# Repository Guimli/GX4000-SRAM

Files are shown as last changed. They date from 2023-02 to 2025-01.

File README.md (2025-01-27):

# GX4000-SRAM

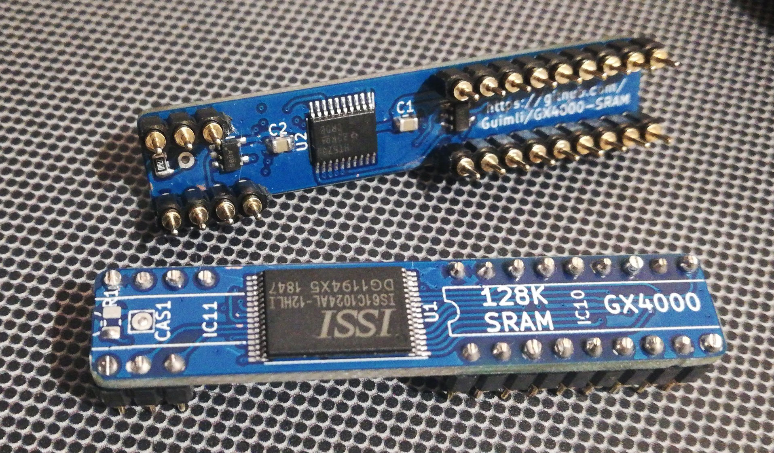
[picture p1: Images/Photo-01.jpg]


RAM replacement mod for GX4000 based on modern RAM. This mod can be used to replace the original RAM of the GX4000. And it is also possible to expand the GX4000's RAM to 128K.

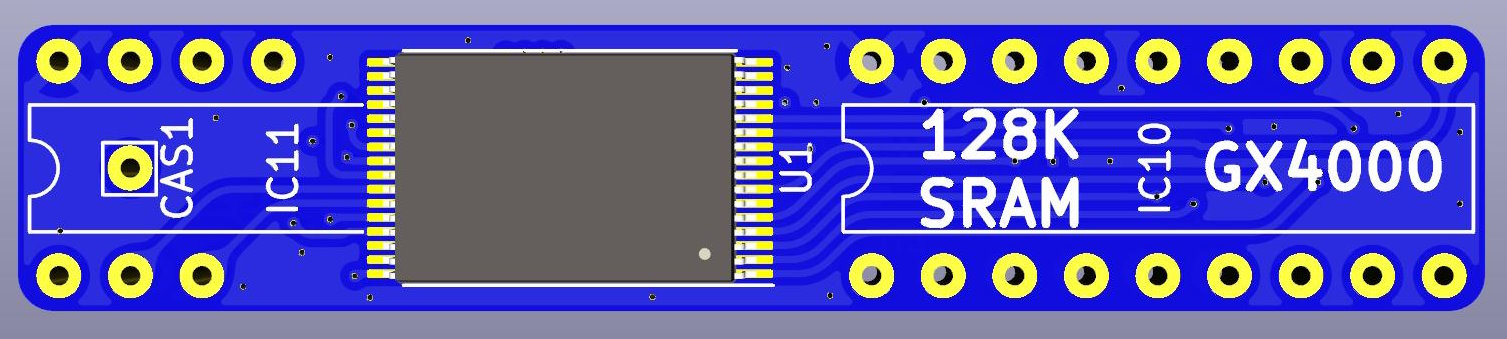
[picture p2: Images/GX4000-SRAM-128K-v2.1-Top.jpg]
Top

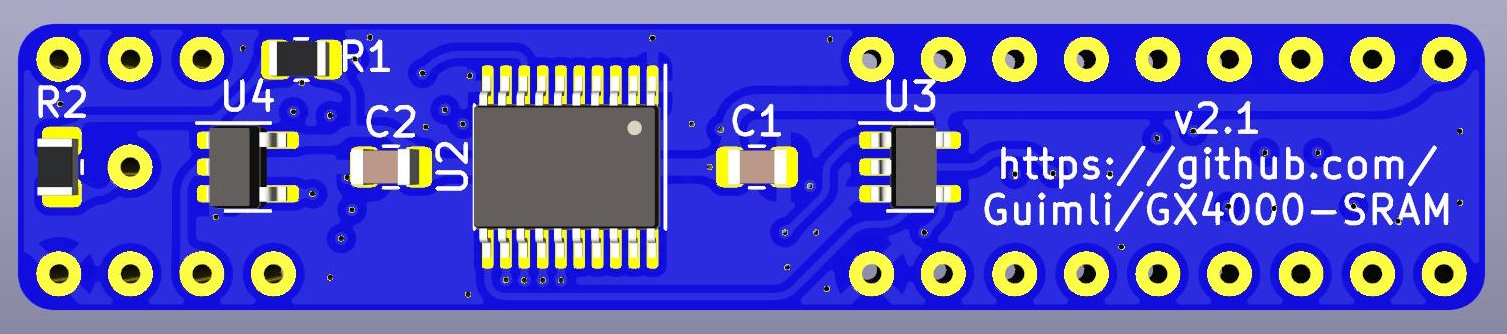
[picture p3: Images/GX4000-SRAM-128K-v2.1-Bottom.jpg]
Bottom


This mod is inspired by the SRAM for C64 on https://github.com/jamarju/c64-sram

Video of the installation of this mod on the Twitch of RetroRedrum :
RetroRedrum - Amstrad GX4000 - 128k S-Ram mod (https://www.youtube.com/watch?v=3vgKoG_qG3Q "RetroRedrum - Amstrad GX4000 - 128k S-Ram mod")

Approximate cost for one RAM mod (costs can be considerably reduced if you build several modules) :

- IS61C1024AL-12HLI : 3.28 €
- SN74HCT573PWR : 0.58 €
- SN74LVC1G08DBVR : 0.36 €
- SN74LVC1G32DBVR : 0.38 €
- R1 & R2 : 0.10 €
- C1 & C2 : 0.84 €
- PCB (minimum 5 + Shipping) : 14.95€
- IC10 & IC11 (Headers 20 pin) : 2.49€
- Round Pinheader (10x 1x40) : 8.19€

Total : 31,32€

I can sell you modules already assembled. But the shipping costs from France are prohibitive...

To enable the 128K mod, add a 10 kΩ resistor between pins 8 and 11 of IC8 (74HC4051).
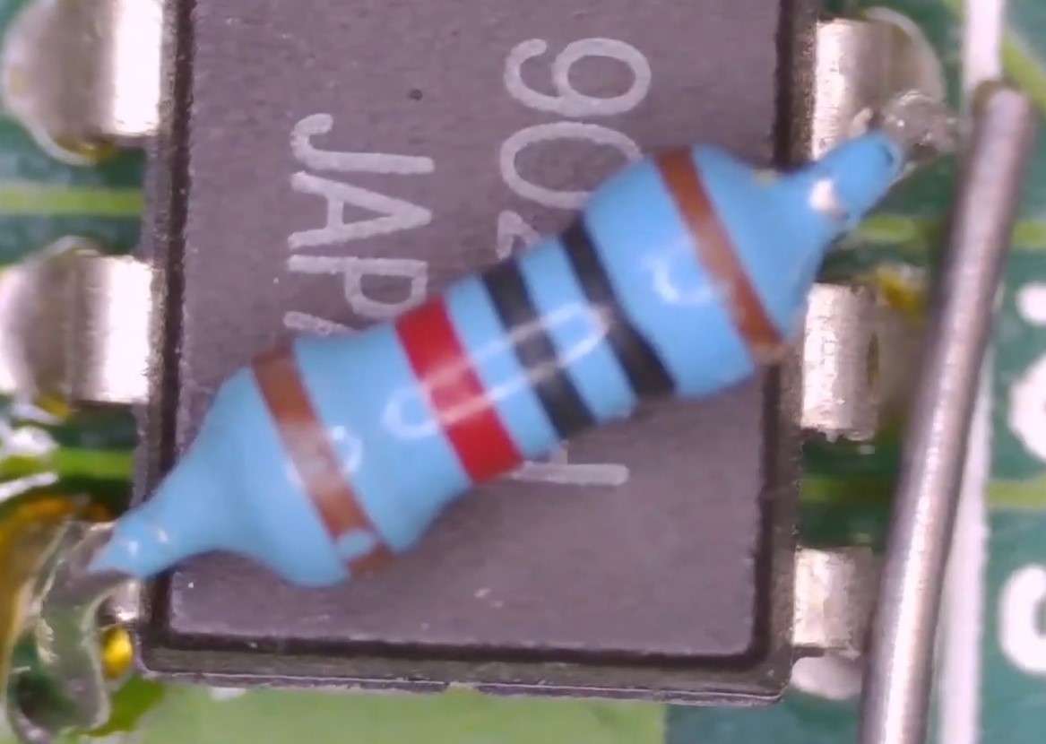
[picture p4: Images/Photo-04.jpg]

And connect pin 91 of the ASIC to the dedicated CAS1 slot on the mod.
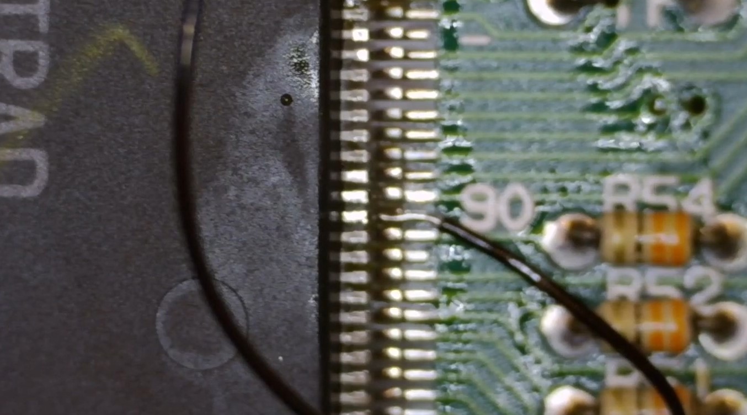
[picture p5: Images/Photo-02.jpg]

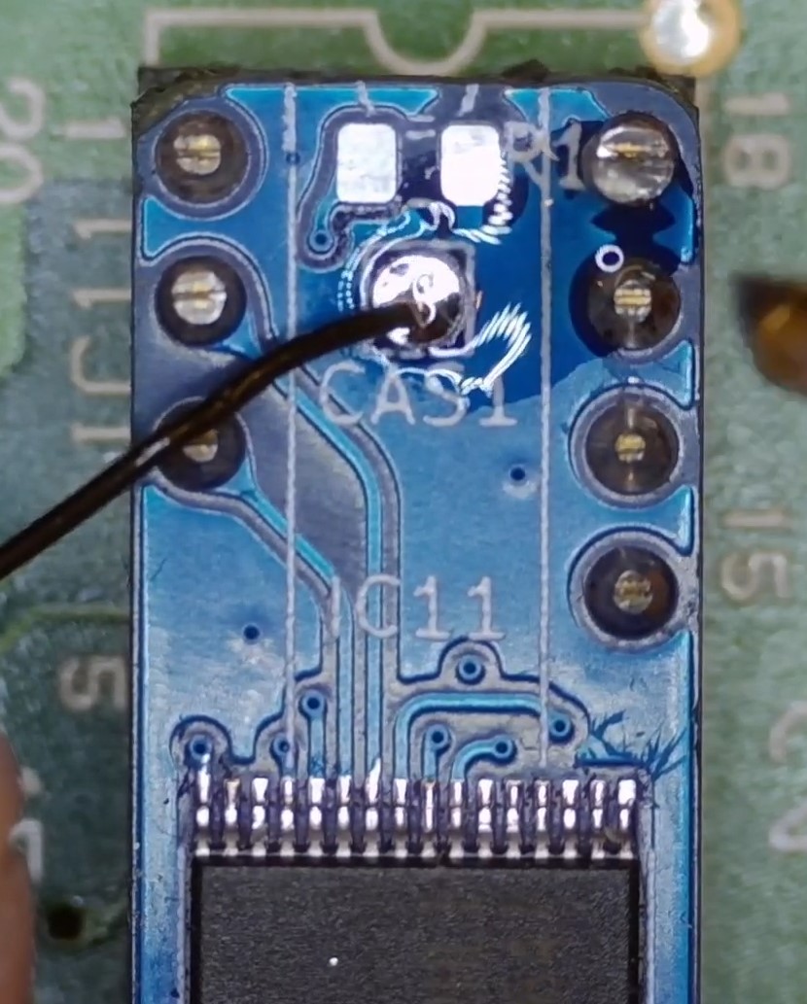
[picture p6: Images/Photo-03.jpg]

(See https://www.cpcwiki.eu/index.php/128k_on_GX-4000 for more information)

## BOM
| Quantity | Description | Part Number | Mouser | Notes |
|:---:|:---|---|---|---|
| 1 | SRAM 1Mbit pin 32 TSOP I-32 | IS61C1024AL-12HLI | [870-61C1024AL-12HLI](https://www.mouser.fr/ProductDetail/ISSI/IS61C1024AL-12HLI?qs=NHlAyh8rbXxX6sVqjKW4FQ%3D%3D) | |
| 1 | 74HCT573 pin 20 TSSOP | SN74HCT573PWR | [595-SN74HCT573PWR](https://www.mouser.fr/ProductDetail/Texas-Instruments/SN74HCT573PWR?qs=CCO124VRWrmt55RoEPLmzg%3D%3D) | |
| 1 | 74LVC1G32 pin 5 SOT-23-5 | SN74LVC1G32DBVR  | [595-SN74LVC1G32DBVR](https://www.mouser.fr/ProductDetail/Texas-Instruments/SN74LVC1G32DBVR?qs=3pnr37ZAbK%2F6ArGi%2FPb2Ng%3D%3D) | |
| 1 | 74LVC1G08 pin 5 SOT-23-5 | SN74LVC1G08DBVR  | [595-SN74LVC1G08DBVR](https://www.mouser.fr/ProductDetail/Texas-Instruments/SN74LVC1G08DBVR?qs=8yeEWhuAOtNjtL049wSCoQ%3D%3D) | |
| 2 | 100nf / 0.1uf Ceramic Capacitor 0805 Size | C0805C104K5RAC7411 | [80-C0805C104K5RACLR](https://www.mouser.fr/ProductDetail/KEMET/C0805C104K5RAC7411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) | Any 100nf 0805 is fine |
| 1 | 47K Ohm resistor 0805 Size | CR0805-JW-473ELF  | [652-CR0805JW-473ELF](https://www.mouser.fr/ProductDetail/Bourns/CR0805-JW-473ELF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) | Any 47KΩ 0805 resistor is fine |
| 1 | 33 Ohm resistor 0805 Size | CR0805-JW-330ELF | [652-CR0805JW-330ELF ](https://www.mouser.fr/ProductDetail/Bourns/CR0805-JW-330ELF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) | Any 33Ω 0805 resistor is fine |

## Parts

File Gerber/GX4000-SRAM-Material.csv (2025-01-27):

Id | Référence | Empreinte | Quantité | Désignation | Fournisseur et réf
1 | U1 | TSOP-I-32_11.8x8mm_P0.5mm | 1 | IS61C1024AL-12HLI
2 | IC10,IC11 | DIP-18_W7.62mm_LongPads | 2 | TMS4464
3 | CAS1 | Pin_D0.7mm_L6.5mm_W1.8mm_FlatFork | 1 | Conn_01x01
4 | U4 | SOT-23-5 | 1 | 74LVC1G08
5 | C1,C2 | C_0805_2012Metric | 2 | 100nF
6 | U2 | TSSOP-20_4.4x6.5mm_P0.65mm | 1 | 74HCT573
7 | U3 | SOT-23-5 | 1 | 74LVC1G32
8 | R1 | R_0805_2012Metric | 1 | 47k
9 | R2 | R_0805_2012Metric | 1 | 33

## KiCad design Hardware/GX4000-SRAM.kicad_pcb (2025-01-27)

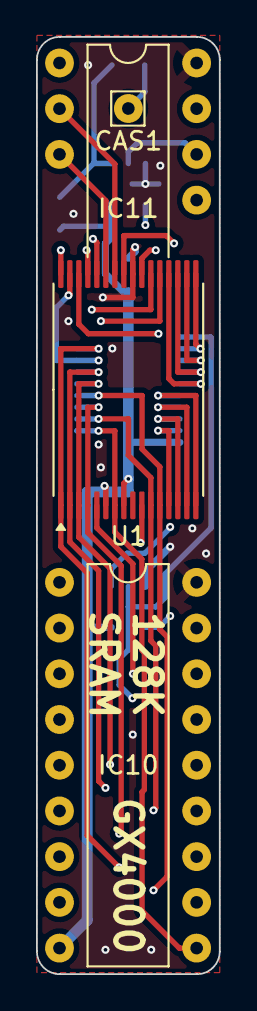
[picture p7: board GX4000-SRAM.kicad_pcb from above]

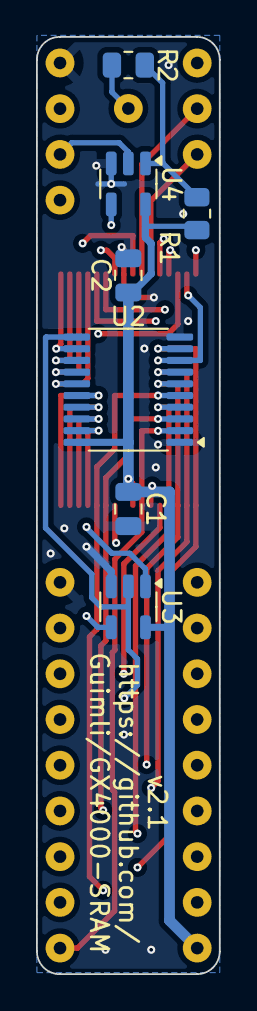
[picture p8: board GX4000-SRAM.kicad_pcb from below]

Board: 4 copper layers, 10.2 x 52.1 mm, 11 parts (7 on the bottom side), 34 nets.

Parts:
C1, C2: 100nF; C_0805_2012Metric
CAS1: Conn_01x01; Pin_D0.7mm_L6.5mm_W1.8mm_FlatFork
IC10, IC11: TMS4464; DIP-18_W7.62mm_LongPads
R1: 47k; R_0805_2012Metric
R2: 33; R_0805_2012Metric
U1: IS61C1024AL-12HLI; TSOP-I-32_11.8x8mm_P0.5mm
U2: SN74HCT573PWR; TSSOP-20_4.4x6.5mm_P0.65mm
U3: 74LVC1G32; SOT-23-5
U4: 74LVC1G08; SOT-23-5

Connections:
/A0: U1.20 (A0), U2.15 (Q4)
/A1: U1.19 (A1), U2.14 (Q5)
/A2: U1.18 (A2), U2.13 (Q6)
/A3: U1.17 (A3), U2.12 (Q7)
/A4: U1.16 (A4), U2.16 (Q3)
/A5: U1.15 (A5), U2.17 (Q2)
/A6: U1.14 (A6), U2.18 (Q1)
/A7: U1.13 (A7), U2.19 (Q0)
/D0: IC10.2 (DQ1), U1.21 (I/O0)
/D1: IC10.3 (DQ2), U1.22 (I/O1)
/D2: IC10.15 (DQ3), U1.23 (I/O2)
/D3: IC10.17 (DQ4), U1.25 (I/O3)
/D4: IC11.2 (DQ1), U1.26 (I/O4)
/D5: IC11.3 (DQ2), U1.27 (I/O5)
/D6: IC11.15 (DQ3), U1.28 (I/O6)
/D7: IC11.17 (DQ4), U1.29 (I/O7)
/MA0: IC10.14 (A0), U1.3 (A8), U2.6 (D4)
/MA1: IC10.13 (A1), U1.2 (A9), U2.7 (D5)
/MA2: IC10.12 (A2), U1.31 (A10), U2.8 (D6)
/MA3: IC10.11 (A3), U1.1 (A11), U2.9 (D7)
/MA4: IC10.8 (A4), U1.12 (A12), U2.5 (D3)
/MA5: IC10.7 (A5), U1.4 (A13), U2.4 (D2)
/MA6: IC10.6 (A6), U1.11 (A14), U2.3 (D1)
/MA7: IC10.10 (A7), U1.7 (A15), U2.2 (D0)
/~CAS0: IC10.16 (~CAS), IC11.16 (~CAS), U1.10 (A16), U4.2
/~CAS1: R1.2, R2.2, U4.1
/~OE: IC10.1 (~G), IC11.1 (~G), U1.32 (~OE)
/~RAS: IC10.5 (~RAS), U2.11 (Load), U3.2
/~WE: IC10.4 (~W), U1.5 (~WE)
GND: C1.2, C2.2, IC10.18 (GND), IC11.18 (GND), U1.24 (GND), U2.1 (OE), U2.10 (GND), U3.3 (GND), U4.3 (GND)
unnamed: CAS1.1, R2.1
unnamed: U1.30 (~CE1), U3.4
unnamed: U3.1, U4.4
VCC: C1.1, C2.1, IC10.9 (VCC), R1.1, U1.6 (CE2), U1.8 (VDD), U2.20 (VCC), U3.5 (VCC), U4.5 (VCC)

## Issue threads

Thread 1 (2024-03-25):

[QUESTION] How to contact

nico7550, 2024-03-25:
Hi, how to contact you to buy the premade ram module ?

Salut, comment te contacter pour acheter des modules de RAM déjà fait ? (accessoirement est-ce que tu accepterais de modder (_résistances, régulateur de tension, ram, acid bypass for BackBit Pro_) ma console contre rémunération ?)

Merci

Nicolas de Cherbourg

Guimli, 2024-03-27:
Bonjour Nicolas.
Je peux t'envoyer un module par la poste. Pour la partie Modding, il faudrait que tu passes par un Twicheur car je n'ai pas encore pu me faire un atelier digne de ce nom (je manque de place). Donc je te conseillerais de voir avec RetroRedrum (il a un module en stock d'avance), AreUBready ou CabriDIY.
Tu peux me contacter par mail : guimli@free.fr

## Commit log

2022-11-08 Fixes the expacement between U10 and U11
    [GX4000-SRAM.kicad_pcb, GX4000-SRAM.kicad_sch]
2022-11-09 Release PCB
    [GX4000-SRAM.kicad_pcb, GX4000-SRAM.kicad_sch]
2025-01-27 Update Kicad version to 8
    - Update Kicad version format
    - Update Footprint
    - Add JLCPCB component reference
    - Add BOM in description
    [GX4000-SRAM-Material.csv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]

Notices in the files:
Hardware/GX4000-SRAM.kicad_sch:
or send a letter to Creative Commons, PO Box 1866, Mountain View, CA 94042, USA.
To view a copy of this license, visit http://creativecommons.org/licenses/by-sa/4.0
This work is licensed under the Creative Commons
